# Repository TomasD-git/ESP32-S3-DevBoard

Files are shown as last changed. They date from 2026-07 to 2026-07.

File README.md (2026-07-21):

# ESP32-S3-DevBoard
**Normal ESP32 S3 DevBoard, supports any firmware of normal esp32 s3, has antenna**    

<details>
<summary>BOM</summary>

| BOM Name | Purpose | Quantity | Total Cost (USD) | Link | Distributor |
|---|---|---|---|---|---|
| PCB + stencil | all components are on this | 1 | 17 | https://jlcpcb.com | jlcpcb |
| ALL components | all components that are on pcb | 1 | 20 | https://lcsc.com | lcsc |
| | | Total cost | 37 | | |

</details>

# Pictures  
**Schematic**   
  
**PCB**  
  
**3D Viewer (Top view)**    
  
**3D Viewer (Bottom view)**  


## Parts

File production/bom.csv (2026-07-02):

Designator | Footprint | Quantity | Value | LCSC Part #
AE1 | ANT-SMD_L3.2-W1.6 | 1 | 2450AT18A100E | C89334
C1, C10, C15, C2, C20, C7, C9 | 0201 | 7 | 100nF | C190183
C11 | 0201 | 1 | 1pF | C85893
C12 | 0201 | 1 | 1.2pF | C22374839
C13, C14 | 0201 | 2 | 11pF | C384958
C16, C18, C4 | 0603 | 3 | 10uF | C711098
C17 | 0805 | 1 | 22uF | C98190
C19, C3, C6, C8 | 0402 | 4 | 1uF | C106254
C21 | 0201 | 1 | 1.8pF | C22374841
C5 | 0201 | 1 | 10nF | C272853
J1, J2 | PinHeader_1x20_P2.54mm_Vertical | 2 | Conn_01x20
J3 | PinHeader_1x02_P2.54mm_Vertical | 1 | Conn_01x02
L1 | 0201 | 1 | 2.0nH | C86125
L2 | 0201 | 1 | 3.9nH | C76756
L3 | 0201 | 1 | 24nH | C275178
L4 | 0201 | 1 | 2.7nH | C7216765
L5 | 0201 | 1 | 2nH | C86125
R1 | 0201 | 1 | 499 | C138137
R2 | 0201 | 1 | 10K | C473048
R3, R4 | 0201 | 2 | 5.1K | C270344
R5, R6 | 0201 | 2 | 22 | C142011
SW1, SW2 | SW-SMD_L3.9-W3.0-P4.45 | 2 | TS-1088-AR02016 | C720477
U1 | QFN-56_L7.0-W7.0-P0.40-TL-EP4.0 | 1 | ESP32-S3 | C2913194
U3 | CRYSTAL-SMD_4P-L3.2-W2.5-BL | 1 | L327S400H11L | C5261245
U4 | SOT-223-4_L6.5-W3.5-P2.30-LS7.0-BR | 1 | AMS1117-3.3_C347222 | C347222
U5 | USB-C-SMD_G-SWITCH_GT-USB-7010ASV | 1 | GT-USB-7010ASV | C2988369

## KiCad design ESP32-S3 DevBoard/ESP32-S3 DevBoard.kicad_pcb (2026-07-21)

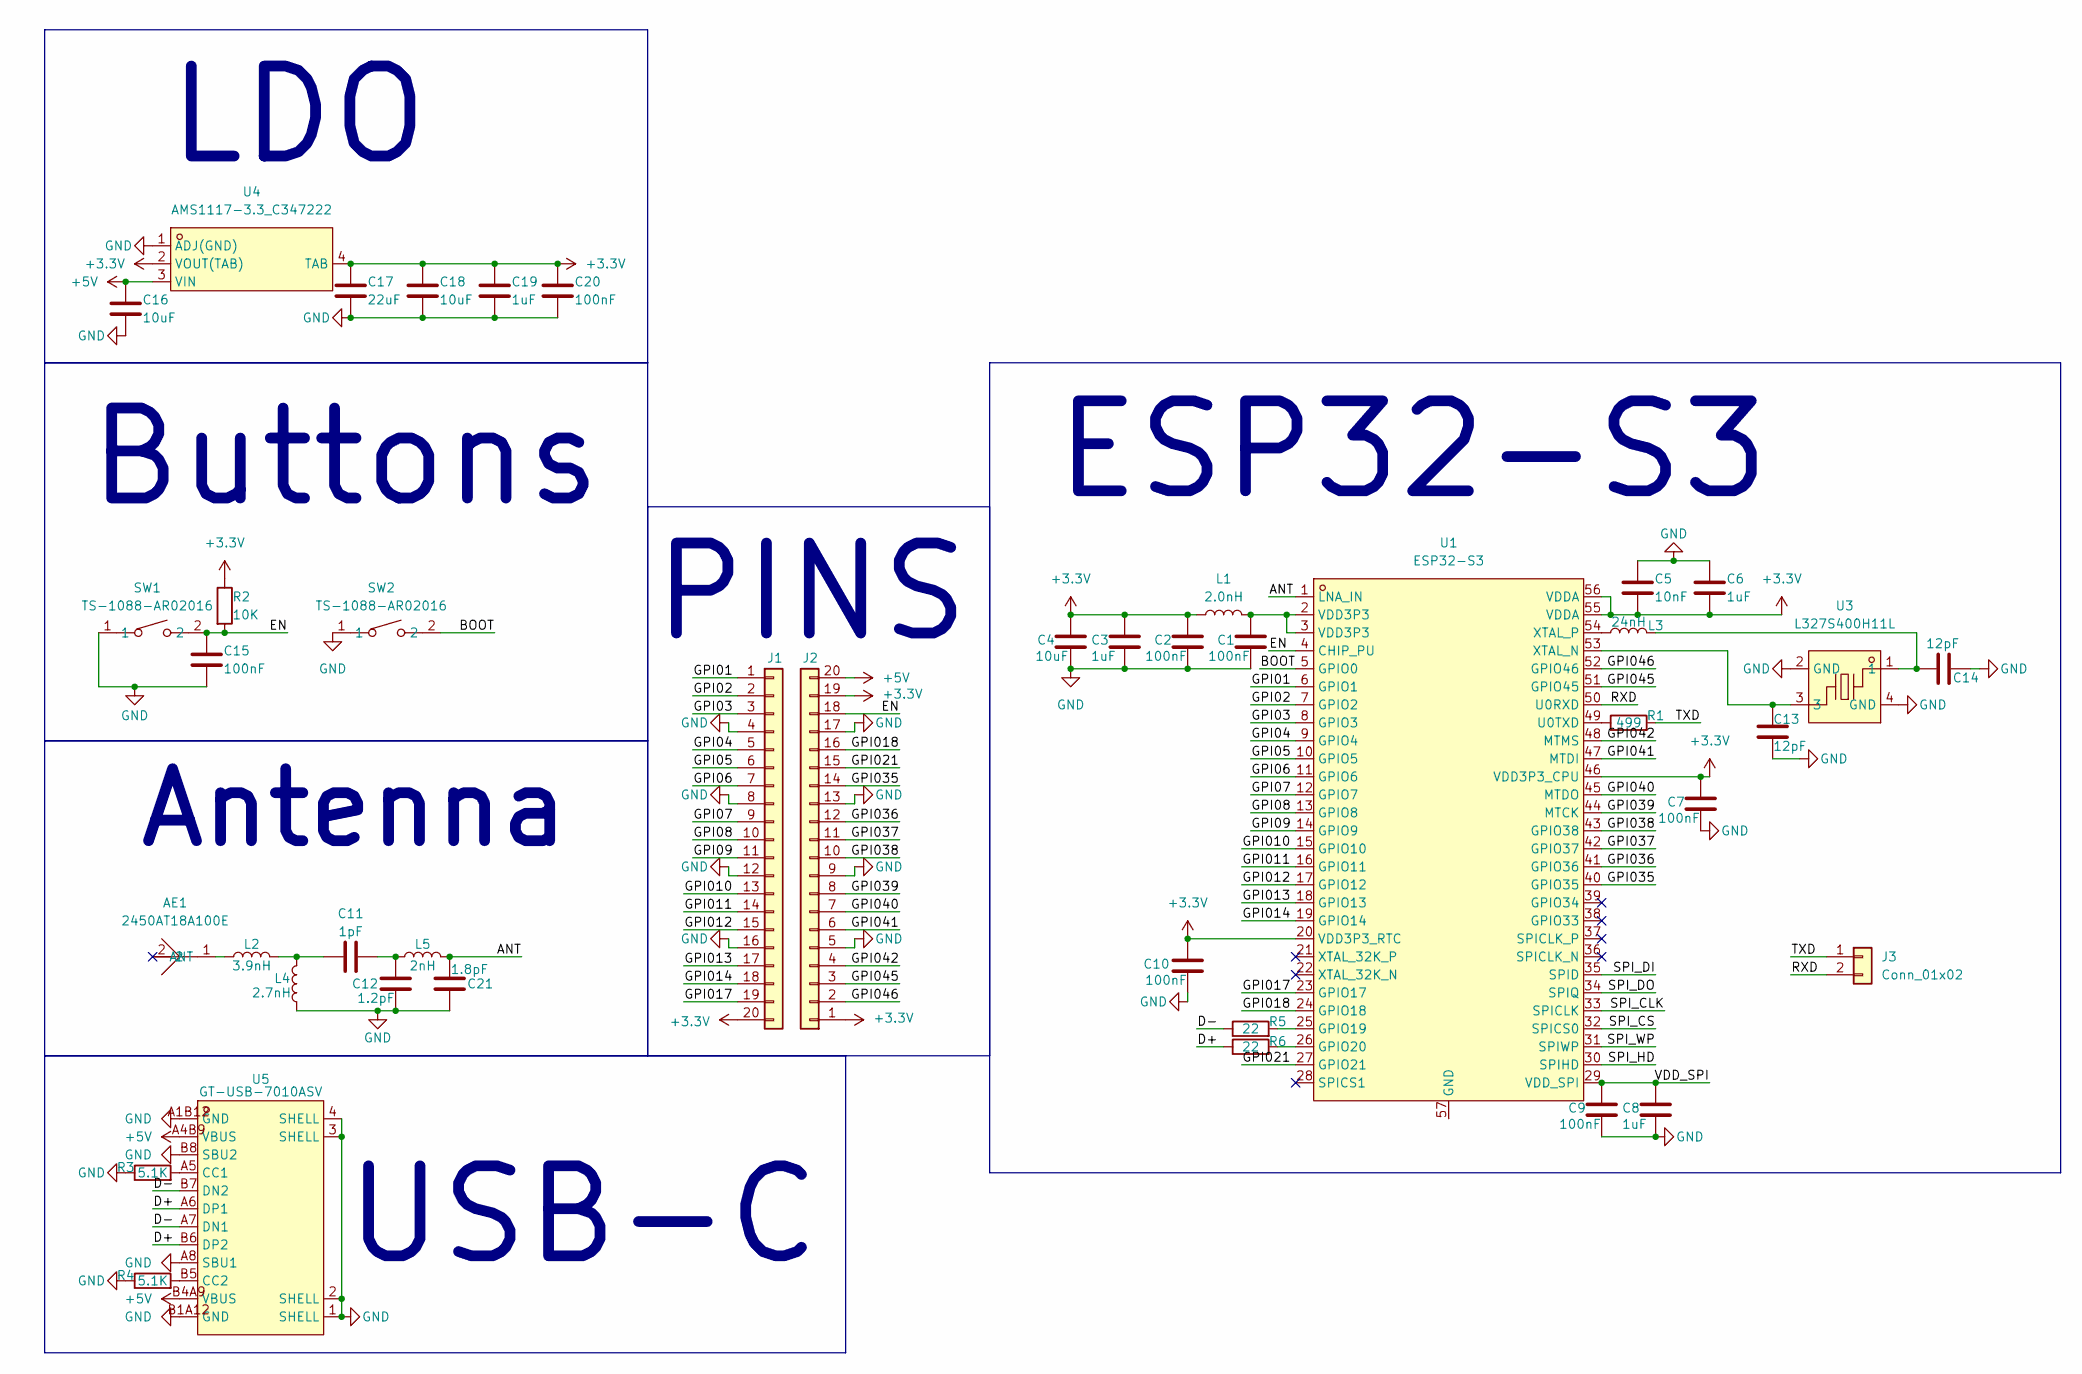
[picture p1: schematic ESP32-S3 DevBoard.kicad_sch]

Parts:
AE1: 2450AT18A100E; ANT-SMD_L3.2-W1.6; MPN 2450AT18A100E; LCSC Part C89334
C1, C2, C7, C9, C10, C15, C20: 100nF; C_0201_0603Metric
C3, C6, C8, C19: 1uF; C_0402_1005Metric
C4, C16, C18: 10uF; C_0603_1608Metric
C5: 10nF; C_0201_0603Metric
C11: 1pF; C_0201_0603Metric
C12: 1.2pF; C_0201_0603Metric
C13, C14: 12pF; C_0201_0603Metric
C17: 22uF; C_0805_2012Metric
C21: 1.8pF; C_0201_0603Metric
J1, J2: Conn_01x20; PinHeader_1x20_P2.54mm_Vertical
J3: Conn_01x02; PinHeader_1x02_P2.54mm_Vertical
L1: 2.0nH; L_0201_0603Metric
L2: 3.9nH; L_0201_0603Metric
L3: 24nH; L_0201_0603Metric
L4: 2.7nH; L_0201_0603Metric
L5: 2nH; L_0201_0603Metric
R1: 499; R_0201_0603Metric
R2: 10K; R_0201_0603Metric
R3, R4: 5.1K; R_0201_0603Metric
R5, R6: 22; R_0201_0603Metric
SW1, SW2: TS-1088-AR02016; SW-SMD_L3.9-W3.0-P4.45; MPN TS-1088-AR02016; LCSC Part C720477
U1: ESP32-S3; QFN-56_L7.0-W7.0-P0.40-TL-EP4.0; MPN ESP32-S3R8; LCSC Part C2913194
U3: L327S400H11L; CRYSTAL-SMD_4P-L3.2-W2.5-BL; MPN L327S400H11L; LCSC Part C5261245
U4: AMS1117-3.3_C347222; SOT-223-4_L6.5-W3.5-P2.30-LS7.0-BR; MPN AMS1117-3.3; LCSC Part C347222
U5: GT-USB-7010ASV; USB-C-SMD_G-SWITCH_GT-USB-7010ASV; MPN GT-USB-7010ASV; LCSC Part C2988369

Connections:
+3.3V: C2.1, C3.1, C4.1, C5.2, C6.2, C7.1, C10.1, C17.1, C18.1, C19.1, C20.1, J1.20, J2.1, J2.19, L1.1, R2.1, U1.20 (VDD3P3_RTC), U1.46 (VDD3P3_CPU), U1.55 (VDDA), U1.56 (VDDA), U4.2 (VOUT(TAB)), U4.4 (TAB)
+5V: C16.1, J2.20, U4.3 (VIN), U5.A4B9 (VBUS), U5.B4A9 (VBUS)
/ANT: C21.2, L5.2, U1.1 (LNA_IN)
/BOOT: SW2.2, U1.5 (GPIO0)
/D+: R6.1, U5.A6 (DP1), U5.B6 (DP2)
/D-: R5.1, U5.A7 (DN1), U5.B7 (DN2)
/EN: C15.1, J2.18, R2.2, SW1.2, U1.4 (CHIP_PU)
/GPI01: J1.1, U1.6 (GPIO1)
/GPI02: J1.2, U1.7 (GPIO2)
/GPI03: J1.3, U1.8 (GPIO3)
/GPI04: J1.5, U1.9 (GPIO4)
/GPI05: J1.6, U1.10 (GPIO5)
/GPI06: J1.7, U1.11 (GPIO6)
/GPI07: J1.9, U1.12 (GPIO7)
/GPI08: J1.10, U1.13 (GPIO8)
/GPI09: J1.11, U1.14 (GPIO9)
/GPI010: J1.13, U1.15 (GPIO10)
/GPI011: J1.14, U1.16 (GPIO11)
/GPI012: J1.15, U1.17 (GPIO12)
/GPI013: J1.17, U1.18 (GPIO13)
/GPI014: J1.18, U1.19 (GPIO14)
/GPI017: J1.19, U1.23 (GPIO17)
/GPI018: J2.16, U1.24 (GPIO18)
/GPI021: J2.15, U1.27 (GPIO21)
/GPI035: J2.14, U1.40 (GPIO35)
/GPI036: J2.12, U1.41 (GPIO36)
/GPI037: J2.11, U1.42 (GPIO37)
/GPI038: J2.10, U1.43 (GPIO38)
/GPI039: J2.8, U1.44 (MTCK)
/GPI040: J2.7, U1.45 (MTDO)
/GPI041: J2.6, U1.47 (MTDI)
/GPI042: J2.4, U1.48 (MTMS)
/GPI045: J2.3, U1.51 (GPIO45)
/GPI046: J2.2, U1.52 (GPIO46)
/RXD: J3.2, U1.50 (U0RXD)
/SPI_CLK: U1.33 (SPICLK)
/SPI_CS: U1.32 (SPICS0)
/SPI_DI: U1.35 (SPID)
/SPI_DO: U1.34 (SPIQ)
/SPI_HD: U1.30 (SPIHD)
/SPI_WP: U1.31 (SPIWP)
/TXD: J3.1, R1.2
/VDD_SPI: C8.1, C9.1, U1.29 (VDD_SPI)
GND: C1.2, C2.2, C3.2, C4.2, C5.1, C6.1, C7.2, C8.2, C9.2, C10.2, C12.2, C13.2, C14.2, C15.2, C16.2, C17.2, C18.2, C19.2, C20.2, C21.1, J1.4, J1.8, J1.12, J1.16, J2.5, J2.9, J2.13, J2.17, L4.1, R3.1, R4.1, SW1.1, SW2.1, U3.2 (GND), U3.4 (GND), U4.1 (ADJ(GND)), U5.1 (SHELL), U5.2 (SHELL), U5.3 (SHELL), U5.4 (SHELL), U5.A1B12 (GND), U5.A8 (SBU1), U5.B1A12 (GND), U5.B8 (SBU2)
unnamed: AE1.1 (ANT), L2.1
unnamed: C1.1, L1.2, U1.2 (VDD3P3), U1.3 (VDD3P3)
unnamed: C11.1, C12.1, L5.1
unnamed: C11.2, L2.2, L4.2
unnamed: C14.1, L3.2, U3.1
unnamed: R5.2, U1.25 (GPIO19)
unnamed: R6.2, U1.26 (GPIO20)
unnamed: R1.1, U1.49 (U0TXD)
unnamed: C13.1, U1.53 (XTAL_N), U3.3
unnamed: L3.1, U1.54 (XTAL_P)
unnamed: R3.2, U5.A5 (CC1)
unnamed: R4.2, U5.B5 (CC2)

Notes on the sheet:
Antenna
LDO
Buttons
ESP32-S3
PINS
USB-C

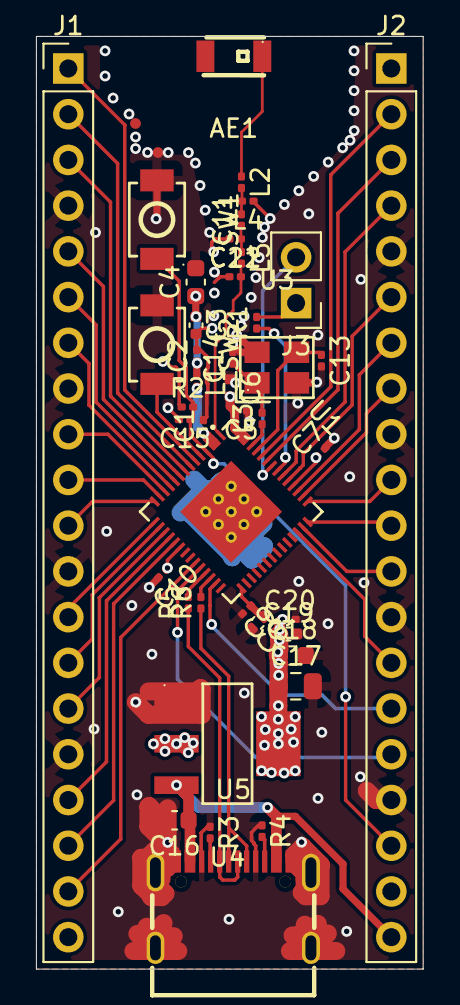
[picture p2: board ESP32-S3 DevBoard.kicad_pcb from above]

Board: 4 copper layers, 21.5 x 51.8 mm, 42 parts (0 on the bottom side), 50 nets.

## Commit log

2026-07-02 Add schematic image to README
    Added schematic image to README.
2026-07-02 Add PCB and 3D viewer images to README
2026-07-02 Add BOM section to README.md
    Added a Bill of Materials (BOM) section to the README with details on components and costs.
2026-07-02 Update README with enhanced description of ESP32 S3 DevBoard
2026-07-21 Revise images in README for clarity and updates
    Updated images in the README with new schematic and 3D viewer views.
2026-07-21 added new updated kicad/PCB files
    [ESP32-S3 DevBoard.kicad_pcb, ESP32-S3 DevBoard.kicad_sch]
2026-07-21 Update README to specify ESP32 S3 in description
